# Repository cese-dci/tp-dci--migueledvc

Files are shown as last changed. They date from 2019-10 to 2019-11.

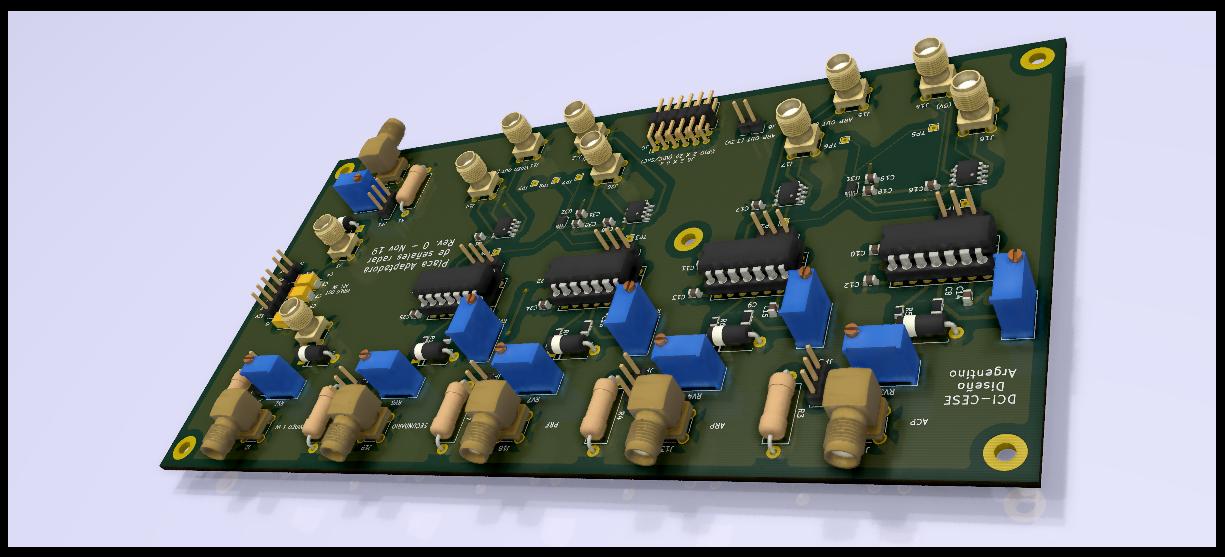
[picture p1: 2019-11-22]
adaptadora/img/4-adaptadora_entradas.jpg

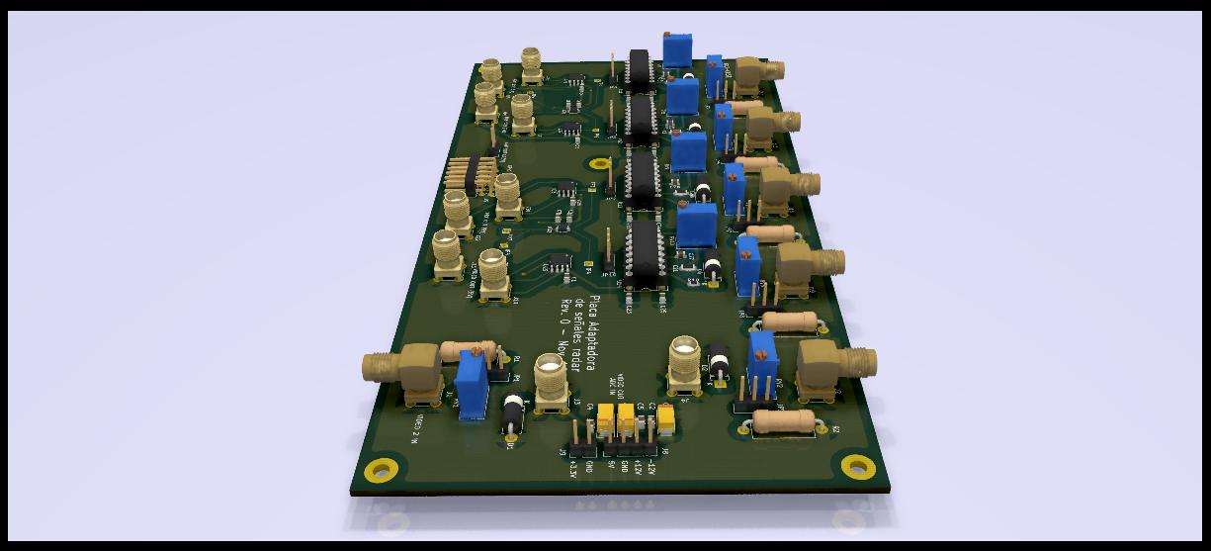
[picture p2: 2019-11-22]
adaptadora/img/6-adaptadora_videos.jpg

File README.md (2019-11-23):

#tp-dci--migueledvc

Placa adaptadora de señales de radar
====================================

+ El presente documento presenta la idea de un circuito adaptador de señales típicas de un radar.

+ No se especifica un modelo de radar en particular.

+ El circuíto es parte del desarrollo de un procesador de radar con tecnología FPGA-SoC. (ADC-SoC de Terasic)

+ Se utiliza para esta placa licencia "BSD 3-clause"

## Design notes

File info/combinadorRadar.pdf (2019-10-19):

# Placa adaptadora de Señales de Radar para la implementación de un combinador radar utilizando tecnología SoC-FPGA

# Introducción

La implementación de un Combinador Radar utilizando tecnología FPGA-SoC necesita de las señales de radar (videos de radar primario, videos de radar secundario, y señales de sincronismo). El sistema debe ser capaz combinar los datos extraídos de un sistema radar (Primario + Secundario) y entregar los datos ya procesados. La digitalización y el procesamiento lo debe realizar la tarjeta ADC-SoC de Terasic y la placa adaptadora debe facilitar las señales deseadas.

# Entradas

### - Videos analógicos (radar primario)

Mediante la emisión de pulsos y el cálculo del tiempo de viaje del pulso que se refleja, se puede conocer la posición de blancos, es el caso de los radares de tipo “primario”

### - Video Digital (radar secundario)

En este caso el radar de tipo secundario emite una señal de pregunta que el blanco debe responder con una nueva emisión y a partir de la cual se pueden extraer la posición (por cálculo del tiempo de viaje del pulso de respuesta) o por transmisión codificada de los datos (altura, código de aeronave, etc).

### - Señales de sincronismo:

- PRF: Pulse Repetition Frequency
En un radar del tipo pulsado es la cantidad de pulsos emitidos en un segundo.
- ACP: Azimuth-Change-Pulses
A partir de un encoder en la antena se cuentan una cantidad fija de pulsos. A partir del contador se deduce el ángulo acimutal. El contador se resetea con la señal ARP o NRP
- ARP: North Reference Pulse or Azimuth Reference Pulse
Señal de paso por el norte

# Salidas

Las salidas de la placa adaptadora que ingresan a la tarjeta ADC-SoC no deben superar los 3.3
V. Para esta placa en particular se agregan salidas duplicadas hacia otros procesadores.

Además se agregan salidas digitales hacia un DAC para verificar el correcto funcionamiento de los conversores A/D, una salida de ARP hacia el servidor de hora y salidas de video digital primario (que ya ha pasado por un filtro digital).

Es decir la placa provee las siguientes salidas:

### Video de Radar Primario Digital (x2)

### Video de Radar Secundario a la ADC/SoC (x1)

### Señales de sincronismo a la ADC/SoC (x1)

PRF

ACP

ARP

### Señales de sincronismo a otros procesadores (x2)

PRF

ACP

ARP

### Señal de ARP al servidor NTP (hora GPS para la ADC/SoC)

# Datos de interés

Ancho típico de blancos en video analógico: 0.5 μs

Ancho de pulso típico señales de sincronismo: 2 μs

Tensiones típicas video analógico: 3 V

Tensiones máximas señales de sincronismo: 40 V

# Tamaño

Se elige un tamaño estándar de PCB. Será determinado durante el diseño del PCB.

Opción empresa argentina: Medidas estandar DAI-ICHI (si es doble capa)

Opción con torno en emprendimiento local (si es simple capa)

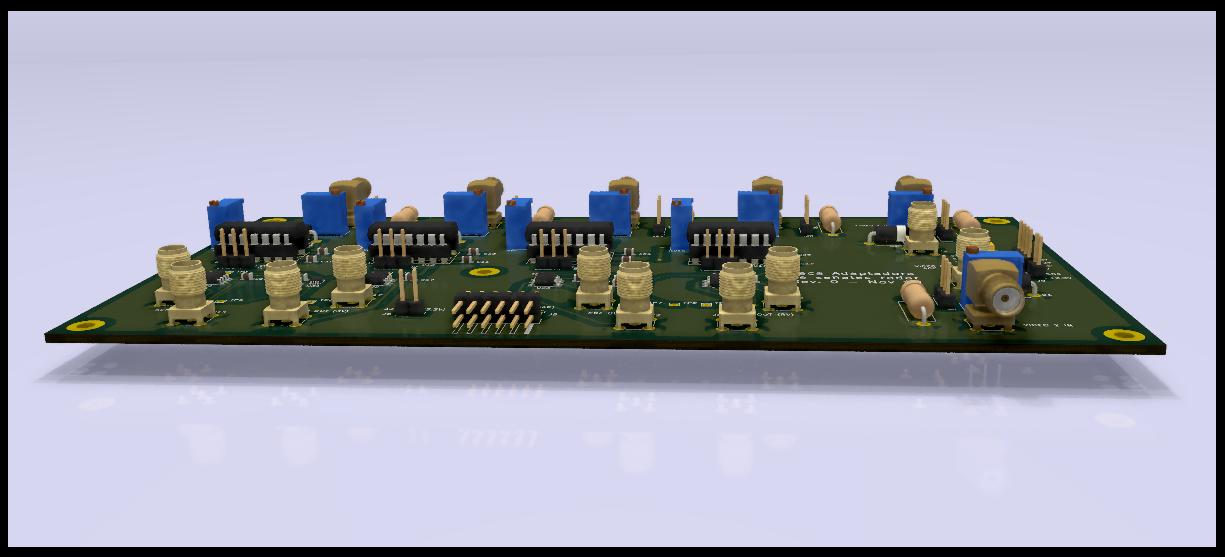
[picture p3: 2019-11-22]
adaptadora/img/5-adaptadora_salidas.jpg

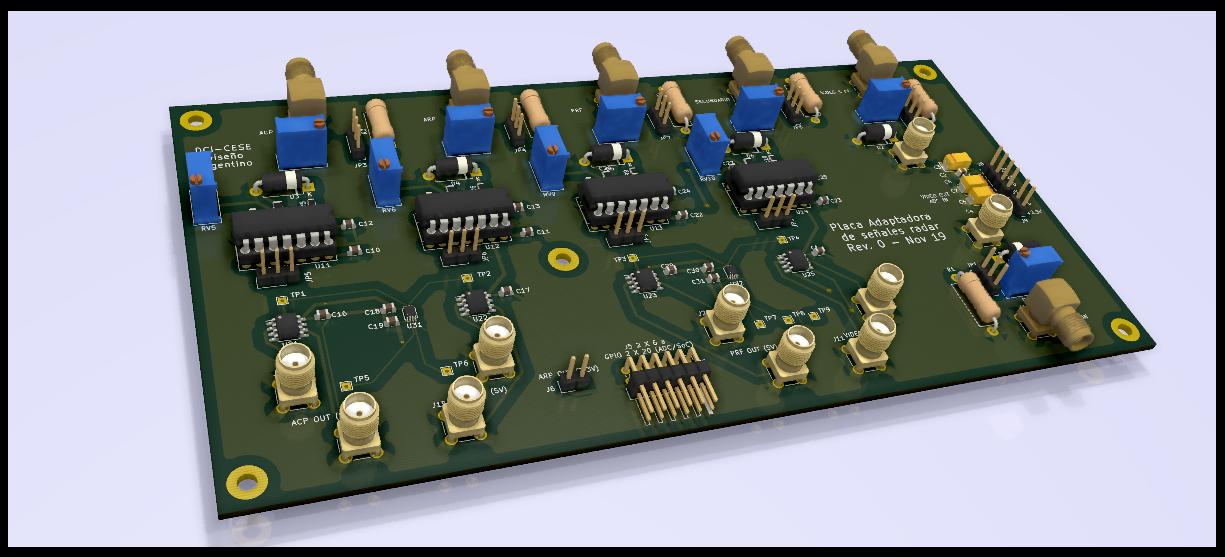
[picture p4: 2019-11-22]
adaptadora/img/3-adaptadora_rot.jpg

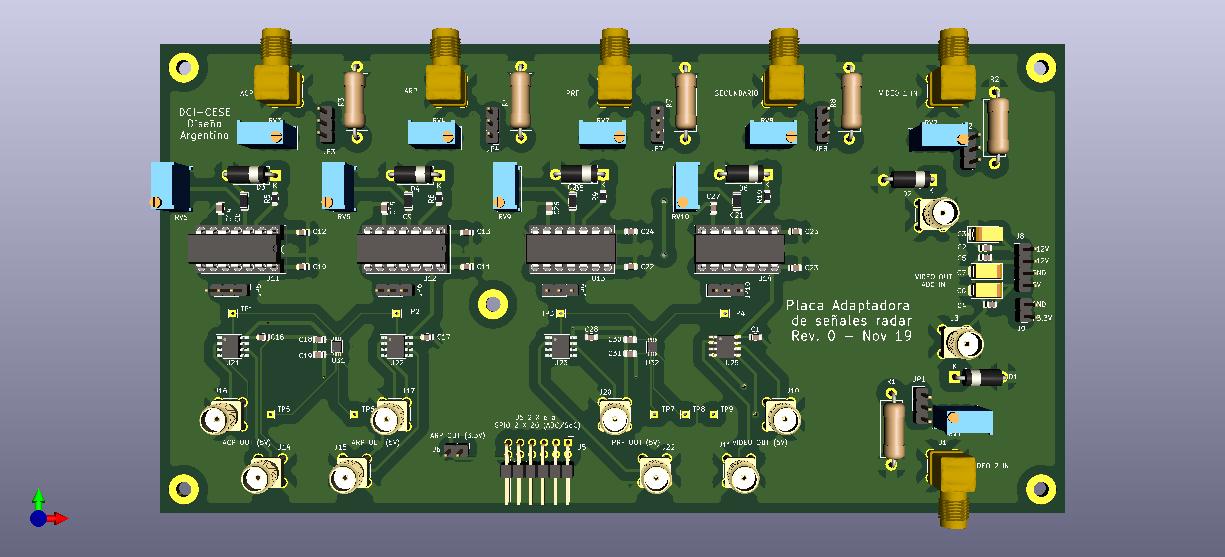
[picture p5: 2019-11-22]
adaptadora/img/1-adaptadora_f.jpg

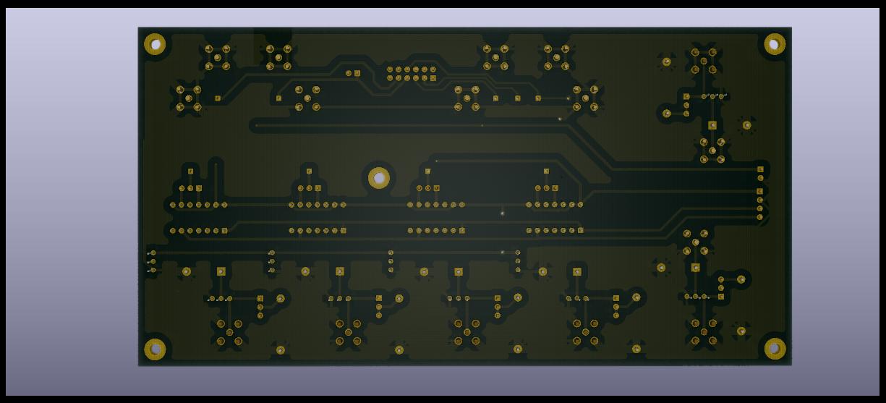
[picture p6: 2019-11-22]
adaptadora/img/2-adaptadora_b.jpg

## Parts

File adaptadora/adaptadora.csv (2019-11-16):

Source: | C:\Users\delar\tp-dci--migueledvc\adaptadora\adaptadora.sch
Date: | 8/11/2019 16:53:56
Tool: | Eeschema (5.1.4)-1
Component Count: | 102
Ref | Value | Footprint | Datasheet | Manufacturer | Vendor
C1 | 0_1uF-50V | Capacitor_SMD:C_0805_2012Metric | ~
C2 | 0_1uF-50V | Capacitor_SMD:C_0805_2012Metric | ~
C3 | 2_2uF-35V | Capacitor_Tantalum_SMD:CP_EIA-6032-28_Kemet-C | ~
C4 | 0_1uF-50V | Capacitor_SMD:C_0805_2012Metric | ~
C5 | 0_1uF-50V | Capacitor_SMD:C_0805_2012Metric | ~
C6 | 2_2uF-35V | Capacitor_Tantalum_SMD:CP_EIA-6032-28_Kemet-C | ~
C7 | 2_2uF-35V | Capacitor_Tantalum_SMD:CP_EIA-6032-28_Kemet-C | ~
C8 | 1uF-16V | Resistor_SMD:R_1206_3216Metric | ~
C9 | 1uF-16V | Resistor_SMD:R_1206_3216Metric | ~
C10 | 0_1uF-50V | Capacitor_SMD:C_0805_2012Metric | ~
C11 | 0_1uF-50V | Capacitor_SMD:C_0805_2012Metric | ~
C12 | 0_1uF-50V | Capacitor_SMD:C_0805_2012Metric | ~
C13 | 0_1uF-50V | Capacitor_SMD:C_0805_2012Metric | ~
C14 | 0_1uF-50V | Capacitor_SMD:C_0805_2012Metric | ~
C15 | 0_1uF-50V | Capacitor_SMD:C_0805_2012Metric | ~
C16 | 0_1uF-50V | Capacitor_SMD:C_0805_2012Metric | ~
C17 | 0_1uF-50V | Capacitor_SMD:C_0805_2012Metric | ~
C18 | 0_1uF-50V | Capacitor_SMD:C_0805_2012Metric | ~
C19 | 0_1uF-50V | Capacitor_SMD:C_0805_2012Metric | ~
C20 | 1uF-16V | Resistor_SMD:R_1206_3216Metric | ~
C21 | 1uF-16V | Resistor_SMD:R_1206_3216Metric | ~
C22 | 0_1uF-50V | Capacitor_SMD:C_0805_2012Metric | ~
C23 | 0_1uF-50V | Capacitor_SMD:C_0805_2012Metric | ~
C24 | 0_1uF-50V | Capacitor_SMD:C_0805_2012Metric | ~
C25 | 0_1uF-50V | Capacitor_SMD:C_0805_2012Metric | ~
C26 | 0_1uF-50V | Capacitor_SMD:C_0805_2012Metric | ~
C27 | 0_1uF-50V | Capacitor_SMD:C_0805_2012Metric | ~
C28 | 0_1uF-50V | Capacitor_SMD:C_0805_2012Metric | ~
C30 | 0_1uF-50V | Capacitor_SMD:C_0805_2012Metric | ~
C31 | 0_1uF-50V | Capacitor_SMD:C_0805_2012Metric | ~
D1 | D_TVS | Diode_SMD:D_0201_0603Metric | ~
D2 | D_TVS | Diode_SMD:D_0201_0603Metric | ~
D3 | D_TVS | Diode_SMD:D_0201_0603Metric | ~
D4 | D_TVS | Diode_SMD:D_0201_0603Metric | ~
D5 | D_TVS | Diode_SMD:D_0201_0603Metric | ~
D6 | D_TVS | Diode_SMD:D_0201_0603Metric | ~
H1 | MountingHole | MountingHole:MountingHole_3.2mm_M3_Pad | ~
H2 | MountingHole | MountingHole:MountingHole_3.2mm_M3_Pad | ~
H3 | MountingHole | MountingHole:MountingHole_3.2mm_M3_Pad | ~
H4 | MountingHole | MountingHole:MountingHole_3.2mm_M3_Pad | ~
H5 | MountingHole | MountingHole:MountingHole_3.2mm_M3_Pad | ~
J1 | Conn_Coaxial | Connector_Coaxial:SMA_Amphenol_901-144_Vertical | ~
J2 | Conn_Coaxial | Connector_Coaxial:SMA_Amphenol_901-144_Vertical | ~
J3 | Conn_Coaxial | Connector_Coaxial:SMA_Amphenol_901-144_Vertical | ~
J4 | Conn_Coaxial | Connector_Coaxial:SMA_Amphenol_901-144_Vertical | ~
J5 | Conn_02x20_Odd_Even | Connector_PinHeader_2.54mm:PinHeader_2x20_P2.54mm_Horizontal | ~
J6 | Conn_01x02 | Connector_PinHeader_2.54mm:PinHeader_1x02_P2.54mm_Vertical | ~
J7 | Conn_02x20_Odd_Even | Connector_PinHeader_2.00mm:PinHeader_2x20_P2.00mm_Vertical | ~
J8 | Conn_01x04 | Connector_PinHeader_2.54mm:PinHeader_1x04_P2.54mm_Vertical | ~
J9 | Conn_01x02 | Connector_PinHeader_2.54mm:PinHeader_1x02_P2.54mm_Vertical | ~
J10 | Conn_Coaxial | Connector_Coaxial:SMA_Amphenol_901-144_Vertical | ~
J11 | Conn_Coaxial | Connector_Coaxial:SMA_Amphenol_901-144_Vertical | ~
J12 | Conn_Coaxial | Connector_Coaxial:SMA_Amphenol_901-144_Vertical | ~
J13 | Conn_Coaxial | Connector_Coaxial:SMA_Amphenol_901-144_Vertical | ~
J14 | Conn_Coaxial | Connector_Coaxial:SMA_Amphenol_901-144_Vertical | ~
J15 | Conn_Coaxial | Connector_Coaxial:SMA_Amphenol_901-144_Vertical | ~
J16 | Conn_Coaxial | Connector_Coaxial:SMA_Amphenol_901-144_Vertical | ~
J17 | Conn_Coaxial | Connector_Coaxial:SMA_Amphenol_901-144_Vertical | ~
J18 | Conn_Coaxial | Connector_Coaxial:SMA_Amphenol_901-144_Vertical | ~
J19 | Conn_Coaxial | Connector_Coaxial:SMA_Amphenol_901-144_Vertical | ~
J20 | Conn_Coaxial | Connector_Coaxial:SMA_Amphenol_901-144_Vertical | ~
J22 | Conn_Coaxial | Connector_Coaxial:SMA_Amphenol_901-144_Vertical | ~
JP1 | Jumper_3_Open | Jumper:SolderJumper-3_P1.3mm_Open_Pad1.0x1.5mm_NumberLabels | ~
JP2 | Jumper_3_Open | Jumper:SolderJumper-3_P1.3mm_Open_Pad1.0x1.5mm_NumberLabels | ~
JP3 | Jumper_3_Open | Jumper:SolderJumper-3_P1.3mm_Open_Pad1.0x1.5mm_NumberLabels | ~
JP4 | Jumper_3_Open | Jumper:SolderJumper-3_P1.3mm_Open_Pad1.0x1.5mm_NumberLabels | ~
JP5 | Jumper_3_Open | Jumper:SolderJumper-3_P1.3mm_Open_Pad1.0x1.5mm_NumberLabels | ~
JP6 | Jumper_3_Open | Jumper:SolderJumper-3_P1.3mm_Open_Pad1.0x1.5mm_NumberLabels | ~
JP7 | Jumper_3_Open | Jumper:SolderJumper-3_P1.3mm_Open_Pad1.0x1.5mm_NumberLabels | ~
JP8 | Jumper_3_Open | Jumper:SolderJumper-3_P1.3mm_Open_Pad1.0x1.5mm_NumberLabels | ~
JP9 | Jumper_3_Open | Jumper:SolderJumper-3_P1.3mm_Open_Pad1.0x1.5mm_NumberLabels | ~
JP10 | Jumper_3_Open | Jumper:SolderJumper-3_P1.3mm_Open_Pad1.0x1.5mm_NumberLabels | ~
R1 | 50 - 1/2W - 5% | Resistor_THT:R_Axial_DIN0414_L11.9mm_D4.5mm_P15.24mm_Horizontal | ~
R2 | 50 - 1/2W - 5% | Resistor_THT:R_Axial_DIN0414_L11.9mm_D4.5mm_P15.24mm_Horizontal | ~
R3 | 50 - 1/2W - 5% | Resistor_THT:R_Axial_DIN0414_L11.9mm_D4.5mm_P15.24mm_Horizontal | ~
R4 | 50 - 1/2W - 5% | Resistor_THT:R_Axial_DIN0414_L11.9mm_D4.5mm_P15.24mm_Horizontal | ~
R5 | 100 - 1/8W - 5% | Resistor_SMD:R_0805_2012Metric | ~
R6 | 100 - 1/8W - 5% | Resistor_SMD:R_0805_2012Metric | ~
R7 | 50 - 1/2W - 5% | Resistor_THT:R_Axial_DIN0414_L11.9mm_D4.5mm_P15.24mm_Horizontal | ~
R8 | 50 - 1/2W - 5% | Resistor_THT:R_Axial_DIN0414_L11.9mm_D4.5mm_P15.24mm_Horizontal | ~
R9 | 100 - 1/8W - 5% | Resistor_SMD:R_0805_2012Metric | ~
R10 | 100 - 1/8W - 5% | Resistor_SMD:R_0805_2012Metric | ~
RV1 | R_POT | Potentiometer_THT:Potentiometer_Bourns_3296W_Vertical | ~
RV2 | R_POT | Potentiometer_THT:Potentiometer_Bourns_3296W_Vertical | ~
RV3 | R_POT | Potentiometer_THT:Potentiometer_Bourns_3296W_Vertical | ~
RV4 | R_POT | Potentiometer_THT:Potentiometer_Bourns_3296W_Vertical | ~
RV5 | R_POT | Potentiometer_THT:Potentiometer_Bourns_3296W_Vertical | ~
RV6 | R_POT | Potentiometer_THT:Potentiometer_Bourns_3296W_Vertical | ~
RV7 | R_POT | Potentiometer_THT:Potentiometer_Bourns_3296W_Vertical | ~
RV8 | R_POT | Potentiometer_THT:Potentiometer_Bourns_3296W_Vertical | ~
RV9 | R_POT | Potentiometer_THT:Potentiometer_Bourns_3296W_Vertical | ~
RV10 | R_POT | Potentiometer_THT:Potentiometer_Bourns_3296W_Vertical | ~
U11 | LM361MX_NOPB | Package_SO:SOIC-14_3.9x8.7mm_P1.27mm | http://www.ti.com/lit/ds/symlink/lm361.pdf
U12 | LM361MX_NOPB | Package_SO:SOIC-14_3.9x8.7mm_P1.27mm | http://www.ti.com/lit/ds/symlink/lm361.pdf
U13 | LM361MX_NOPB | Package_SO:SOIC-14_3.9x8.7mm_P1.27mm | http://www.ti.com/lit/ds/symlink/lm361.pdf
U14 | LM361MX_NOPB | Package_SO:SOIC-14_3.9x8.7mm_P1.27mm | http://www.ti.com/lit/ds/symlink/lm361.pdf
U21 | TLV2772IDR | Package_SO:SOIC-8_3.9x4.9mm_P1.27mm | http://www.ti.com/lit/ds/symlink/tlv2772.pdf
U22 | TLV2772IDR | Package_SO:SOIC-8_3.9x4.9mm_P1.27mm | http://www.ti.com/lit/ds/symlink/tlv2772.pdf
U23 | TLV2772IDR | Package_SO:SOIC-8_3.9x4.9mm_P1.27mm | http://www.ti.com/lit/ds/symlink/tlv2772.pdf
U25 | TLV2772IDR | Package_SO:SOIC-8_3.9x4.9mm_P1.27mm | http://www.ti.com/lit/ds/symlink/tlv2772.pdf
U31 | SN74LVC2T45DCUR | Package_SO:VSSOP-8_2.4x2.1mm_P0.5mm | http://www.ti.com/lit/ds/symlink/sn74lvc2t45.pdf
U32 | SN74LVC2T45DCUR | Package_SO:VSSOP-8_2.4x2.1mm_P0.5mm | http://www.ti.com/lit/ds/symlink/sn74lvc2t45.pdf

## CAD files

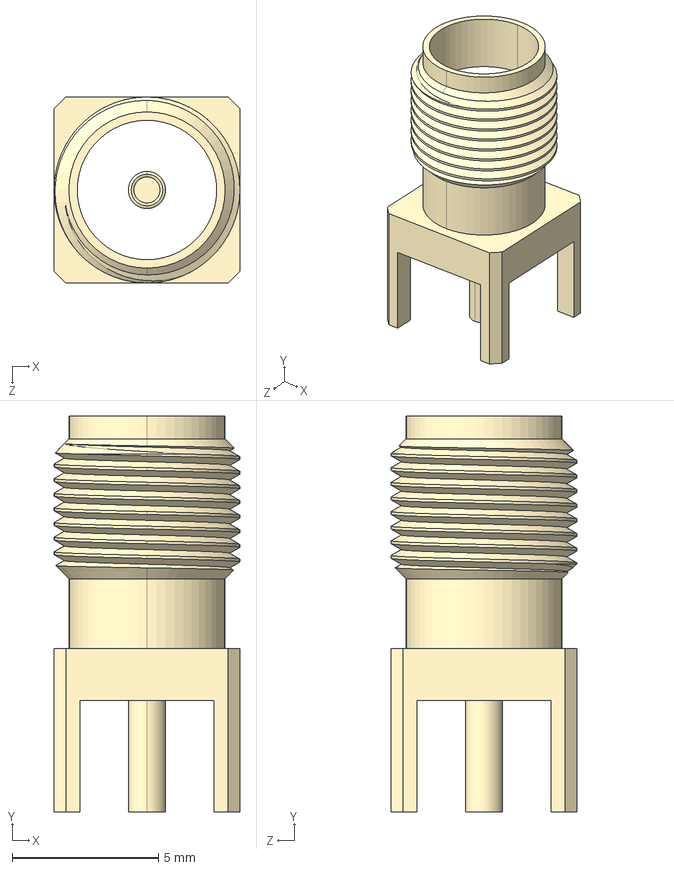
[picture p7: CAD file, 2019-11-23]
adaptadora/shapes3D/User Library-5-1814832-1.STEP
6.35 x 13.5 x 6.35 mm

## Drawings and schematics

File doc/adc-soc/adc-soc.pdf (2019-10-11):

PAGE | CONTENT
01 | Cover Page

ADC-SoC Development Board

02 | Block Diagram
03 | FPGA IO Bank3, 4, 5 and 8
04 | FPGA IO Bank 6 (HPS DDR3)
05 | FPGA IO Bank 7 (HPS Peripheral Device)
06 | FPGA Clock In/Out and Clock Generator
07 | FPGA Configuration and EPCS device
08 | FPGA Power
09 | FPGA Decoupling
10 | USB Blaster II
11 | JTAG Chain
12 | HPS Peripheral : DDR3 SDRAM
13 | HPS Peripheral : UART to USB and SD Card Socket
14 | HPS Peripheral : USB OTG
15 | HPS Peripheral : Gagabit Ethernet
16 | HPS Peripheral : Accelerometer & LTC Expansion Header
17 | HPS Peripheral : Reset Circuit, Button and LED
18 | FPGA : ADC1 (LTC2308) for 8-channel Analog Expansion Header and Arduino Analog input
19 | FPGA : GPIO, Analog and Arduino UNO Expansion Header
20 | FPGA : Button, Switch and LED
21 | FPGA : ADC A
22 | FPGA : ADC B
23 | Power - 1.1V, 5V
24 | Power - 2.5V, 3.3V
25 | Power - 1.2V, 1.5V, 1.8V, 9V

Copyright (c) 2015 by Terasic Inc. Taiwan.
All rights reserved.
No part of this schematic design may be reproduced, duplicated, or used without the prior written permission of Terasic.
ADC-SoC Board

Size Size Size B B B | Document Number Document Number Document Number Cover Page Cover Page Cover Page | Rev Rev Rev A0 A0 A0

Date: Tuesday, December 20, 2016 Tuesday, December 20, 2016 Tuesday, December 20, 2016 | Sheet 1 1 1 of 25 25 25

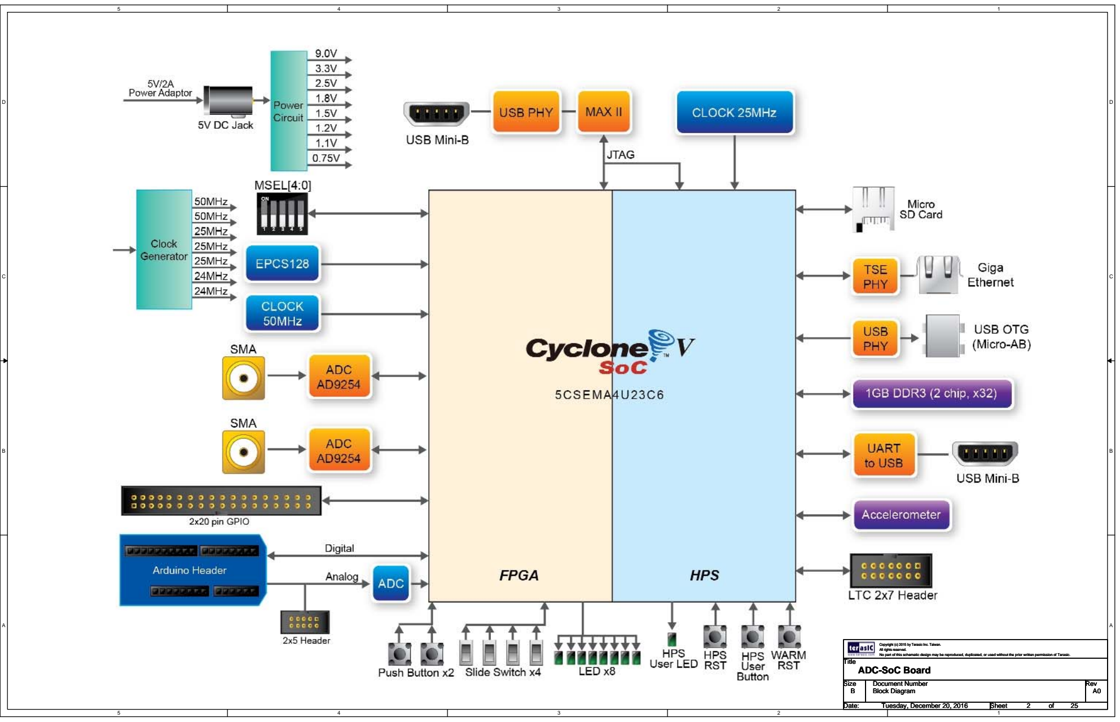
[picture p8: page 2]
Title Title; Title

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

Size Size Size B B B | Document Number Document Number Document Number Block Diagram Block Diagram Block Diagram | Rev Rev Rev A0 A0 A0

Tuesday, December 20, 2016 Tuesday, December 20, 2016 Tuesday, December 20, 2016 | 2 2 2 25 25 25

## CYCLONE V SoC BANK 3

## CYCLONE V SoC BANK 4

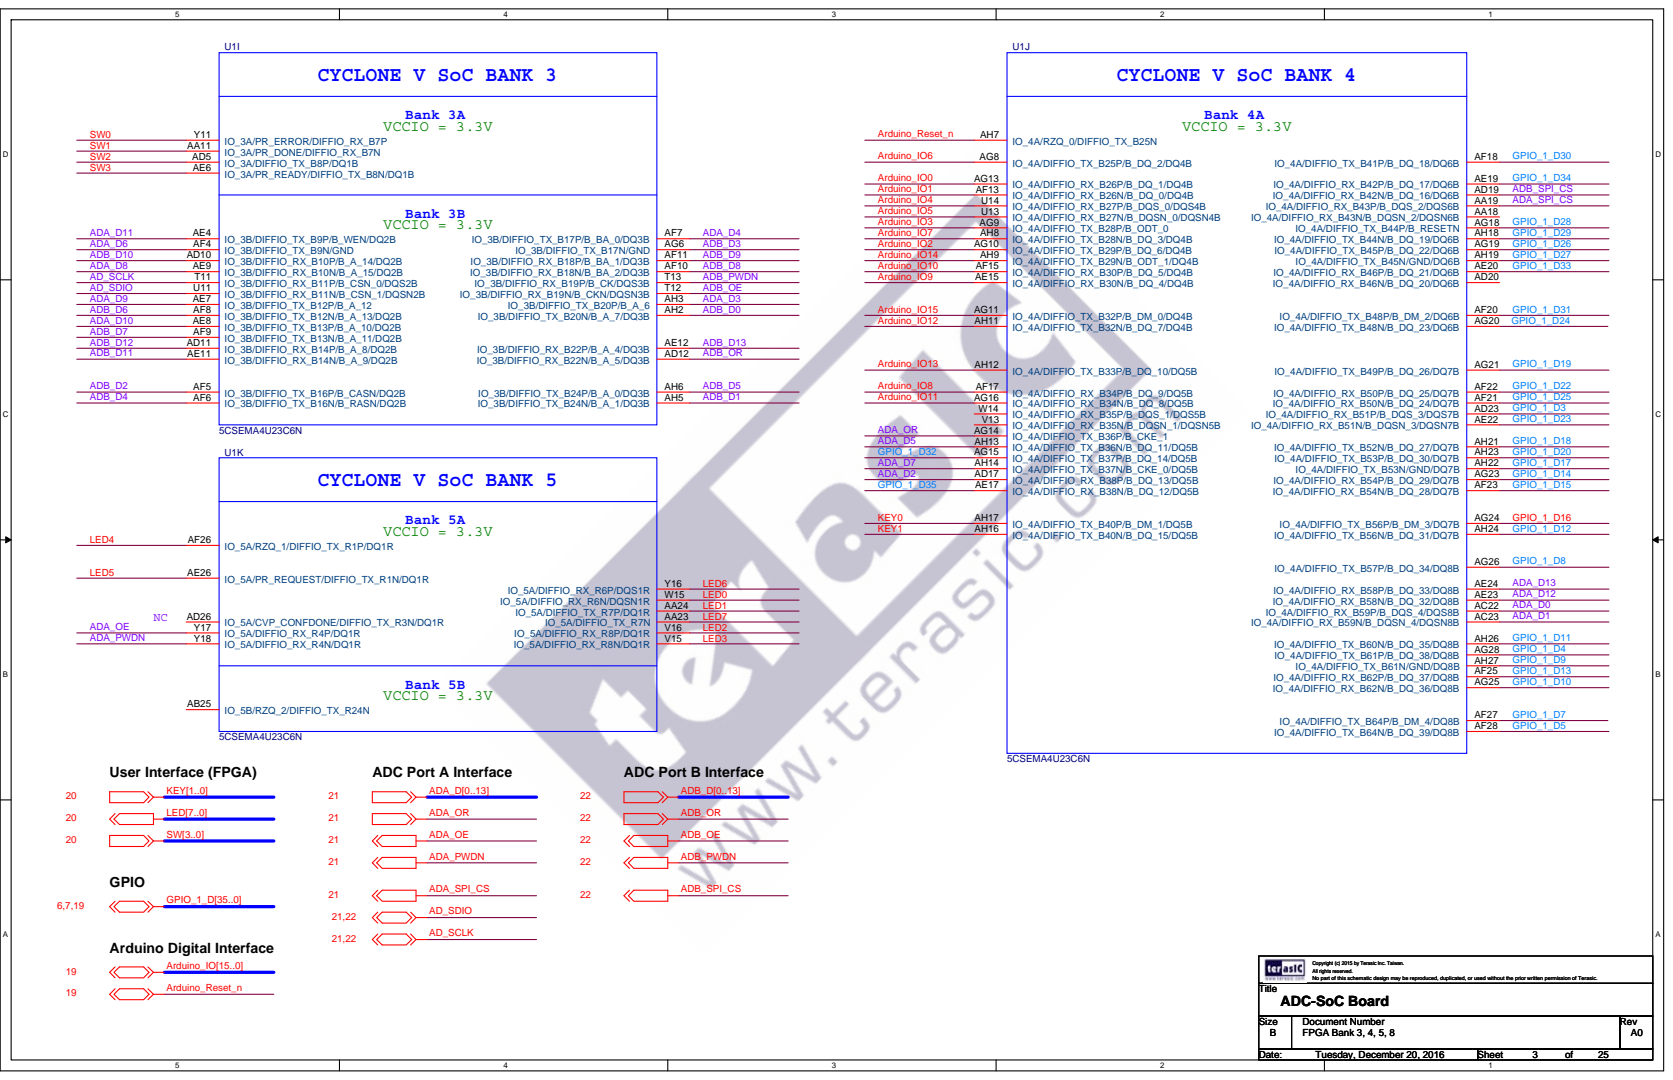
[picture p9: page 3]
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

Size Size Size B B B | Document Number Document Number Document Number FPGA Bank 3, 4, 5, 8 FPGA Bank 3, 4, 5, 8 FPGA Bank 3, 4, 5, 8 | Rev Rev Rev A0 A0 A0

Tuesday, December 20, 2016 Tuesday, December 20, 2016 Tuesday, December 20, 2016 | 3 3 3 25 25 25

## DDR3 Interface (HPS) CYCLONE V SoC BANK 6 (HPS)

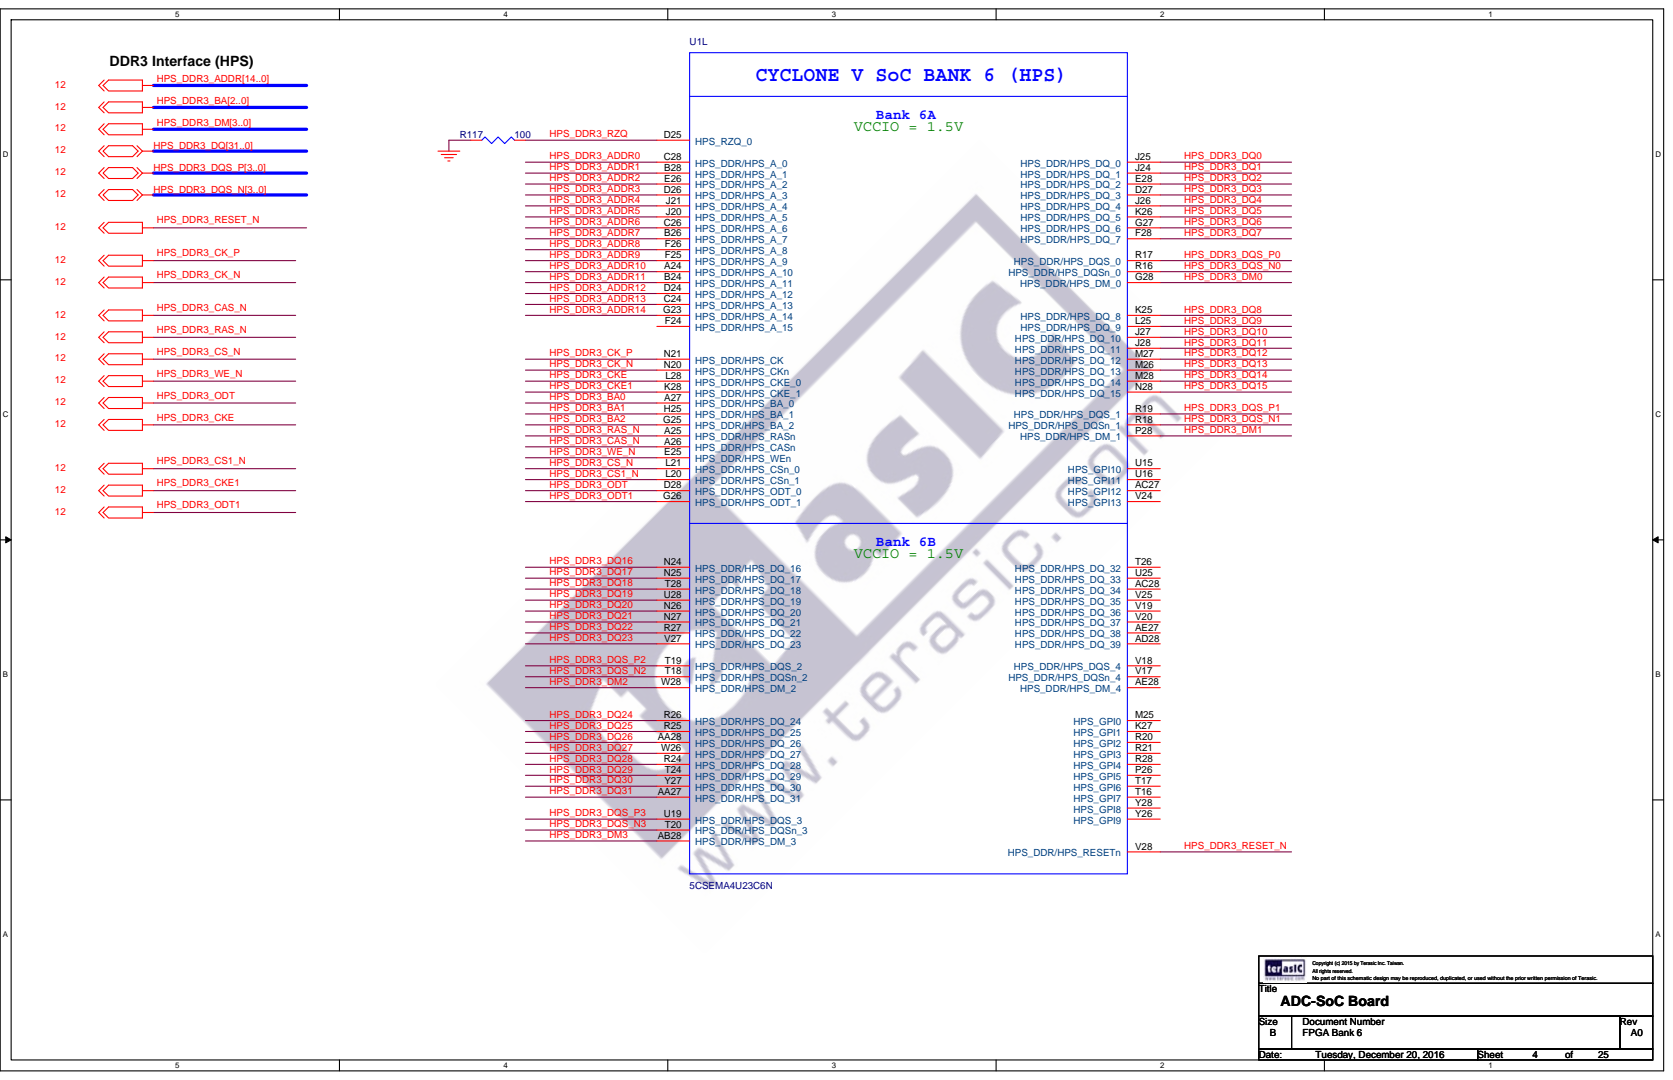
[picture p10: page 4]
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

Size Size Size B B B | Document Number Document Number Document Number FPGA Bank 6 FPGA Bank 6 FPGA Bank 6 | Rev Rev Rev A0 A0 A0

Tuesday, December 20, 2016 Tuesday, December 20, 2016 Tuesday, December 20, 2016 | 4 4 4 25 25 25

## UBS PHY Interface (ULPI)

## Ethernet PHY Interface (RGMII)

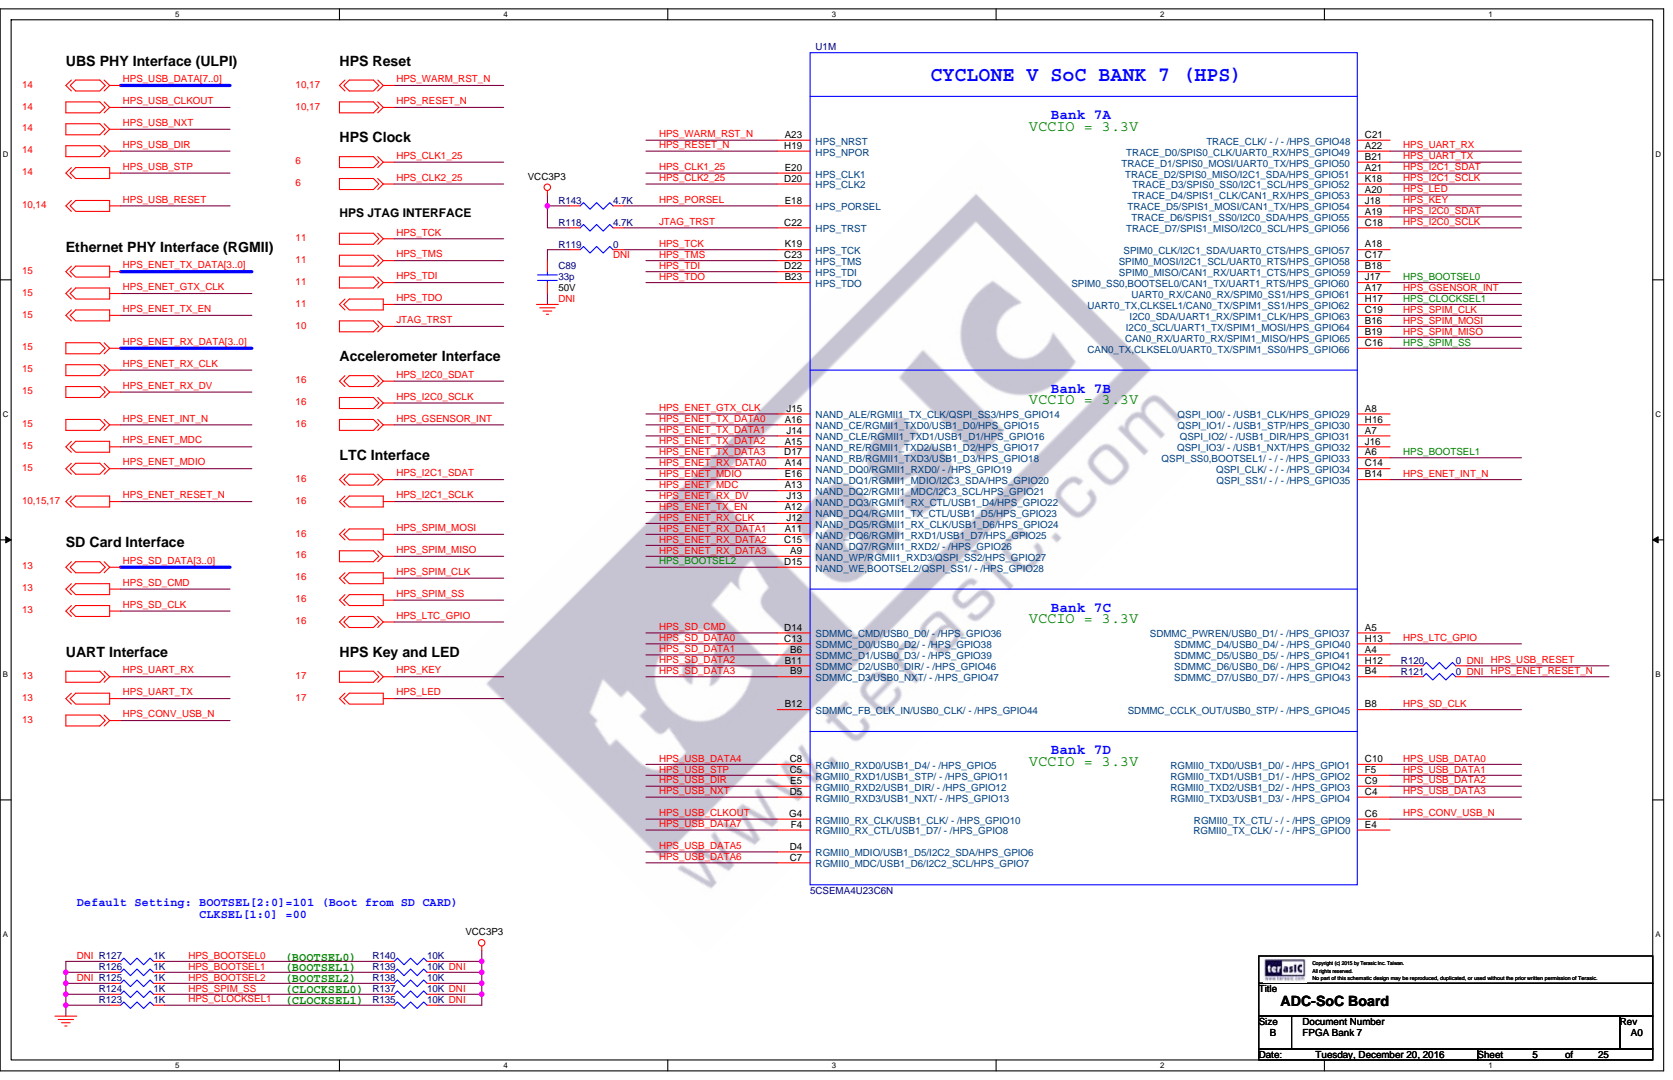
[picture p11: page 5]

CYCLONE V SoC BANK 7 (HPS)

HPS Key and LED

Default Setting: BOOTSEL[2:0]=101 (Boot from SD CARD)

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

Size Size Size B B B | Document Number Document Number Document Number FPGA Bank 7 FPGA Bank 7 FPGA Bank 7 | Rev Rev Rev A0 A0 A0

Tuesday, December 20, 2016 Tuesday, December 20, 2016 Tuesday, December 20, 2016 | 5 5 5 25 25 25

## GPIO

## ADC Port A Interface

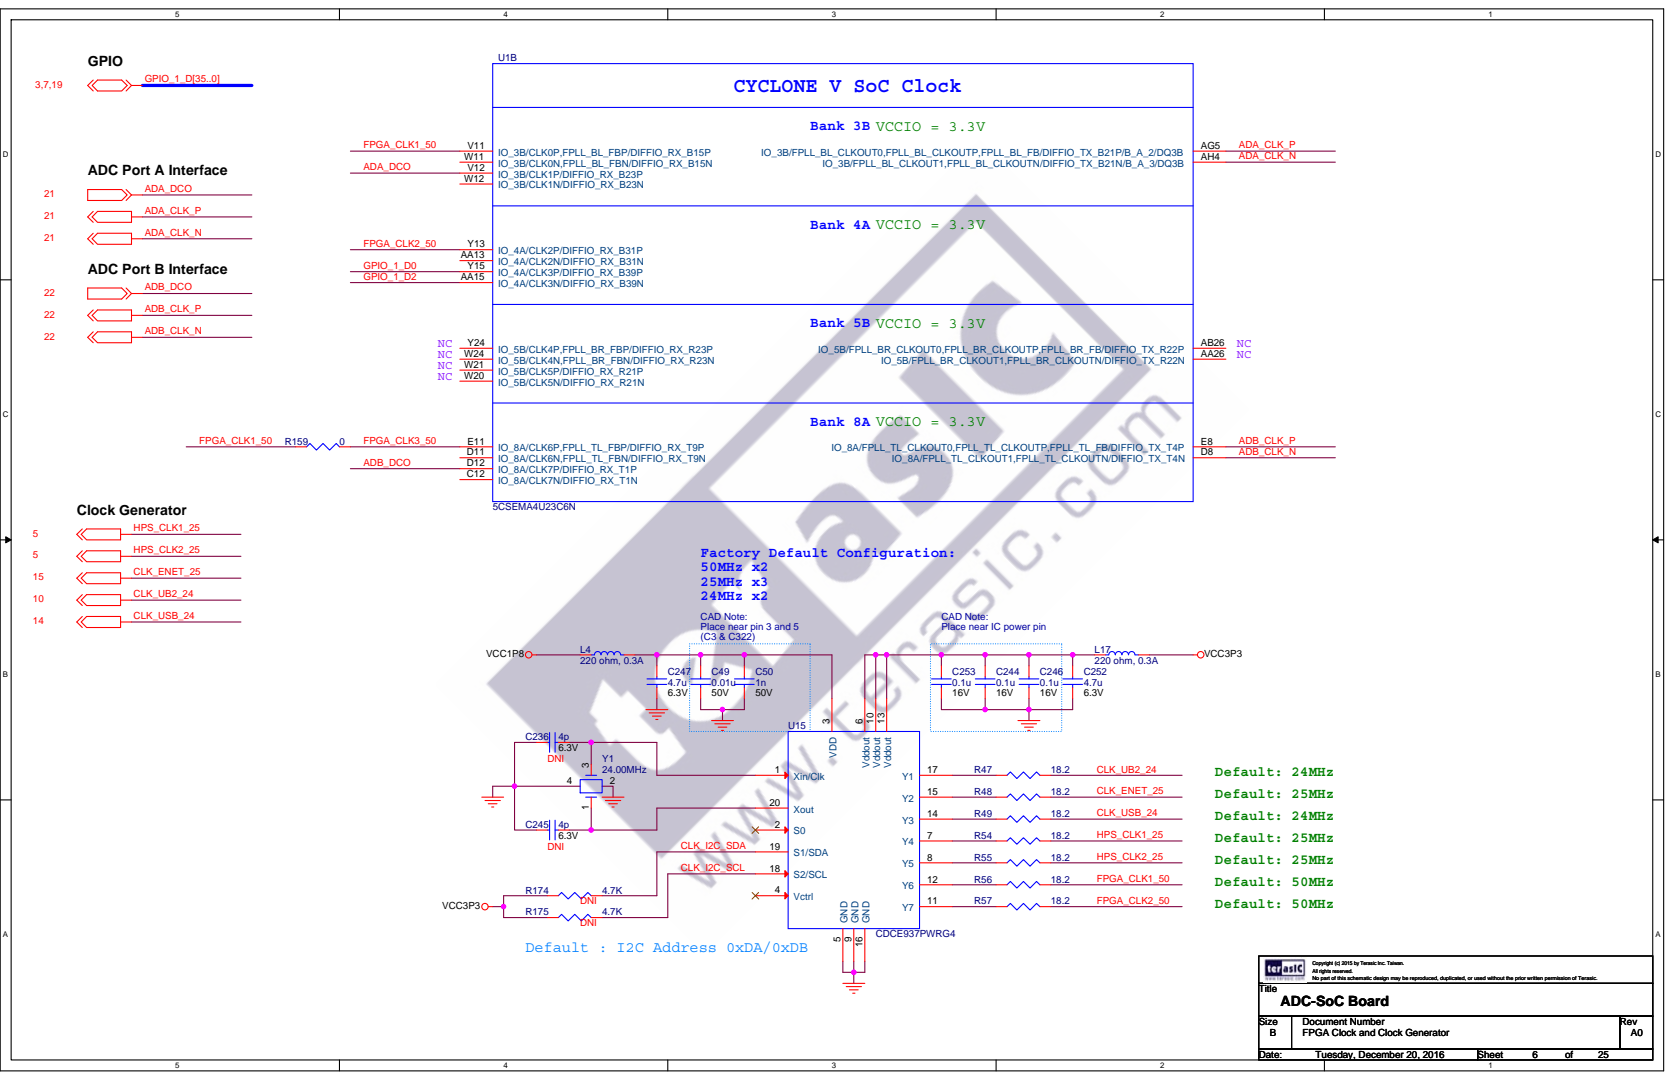
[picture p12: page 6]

CAD Note:
Place near IC power pin

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

Size Size Size B B B | Document Number Document Number Document Number FPGA Clock and Clock Generator FPGA Clock and Clock Generator FPGA Clock and Clock Generator | Rev Rev Rev A0 A0 A0

Tuesday, December 20, 2016 Tuesday, December 20, 2016 Tuesday, December 20, 2016 | 6 6 6 25 25 25

## USB Blaster
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

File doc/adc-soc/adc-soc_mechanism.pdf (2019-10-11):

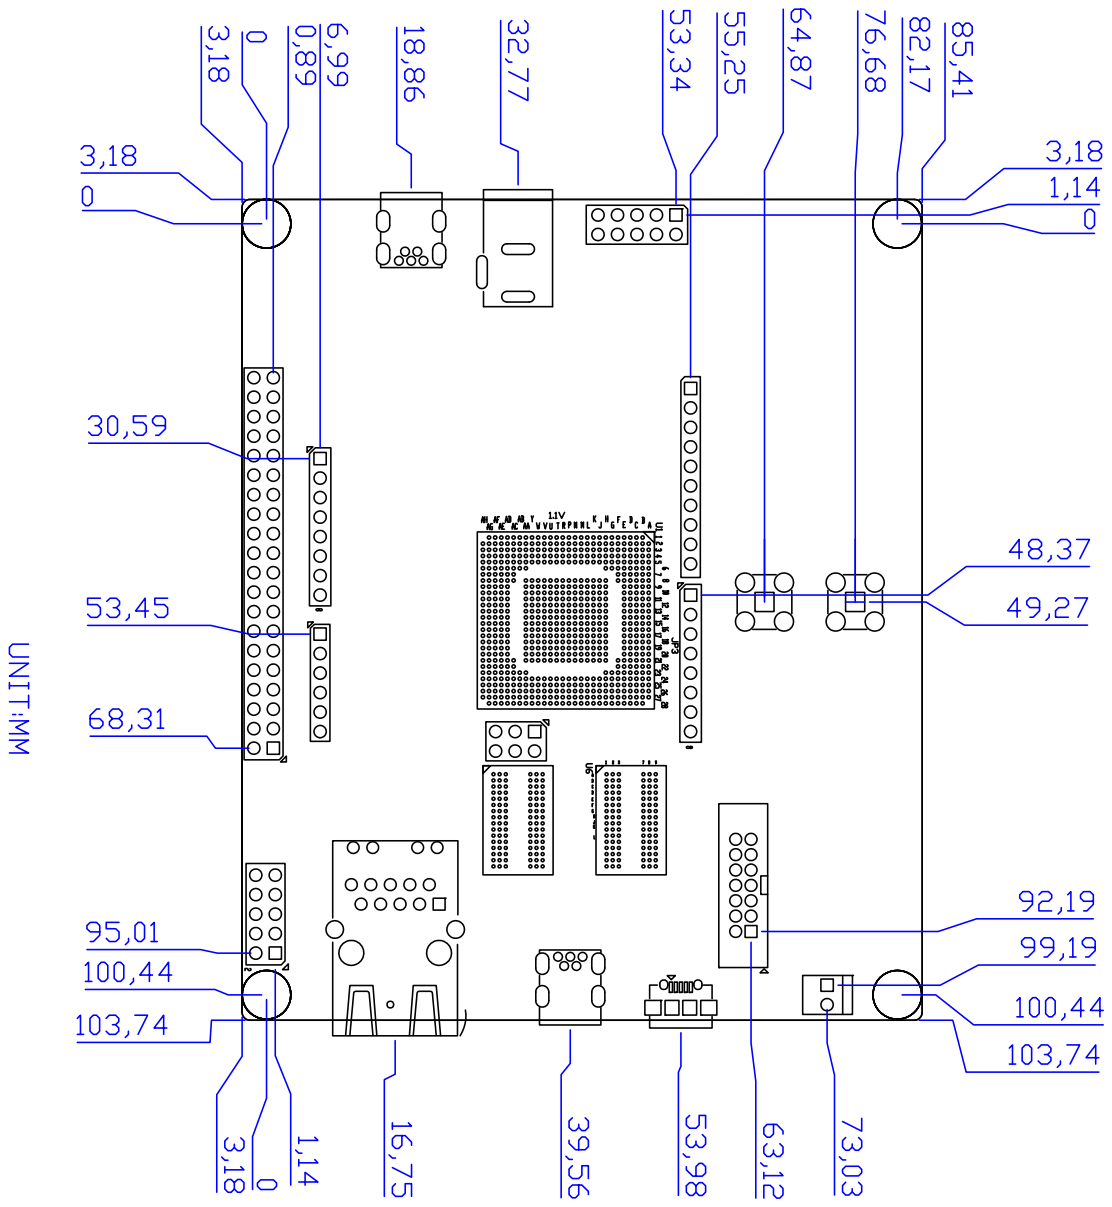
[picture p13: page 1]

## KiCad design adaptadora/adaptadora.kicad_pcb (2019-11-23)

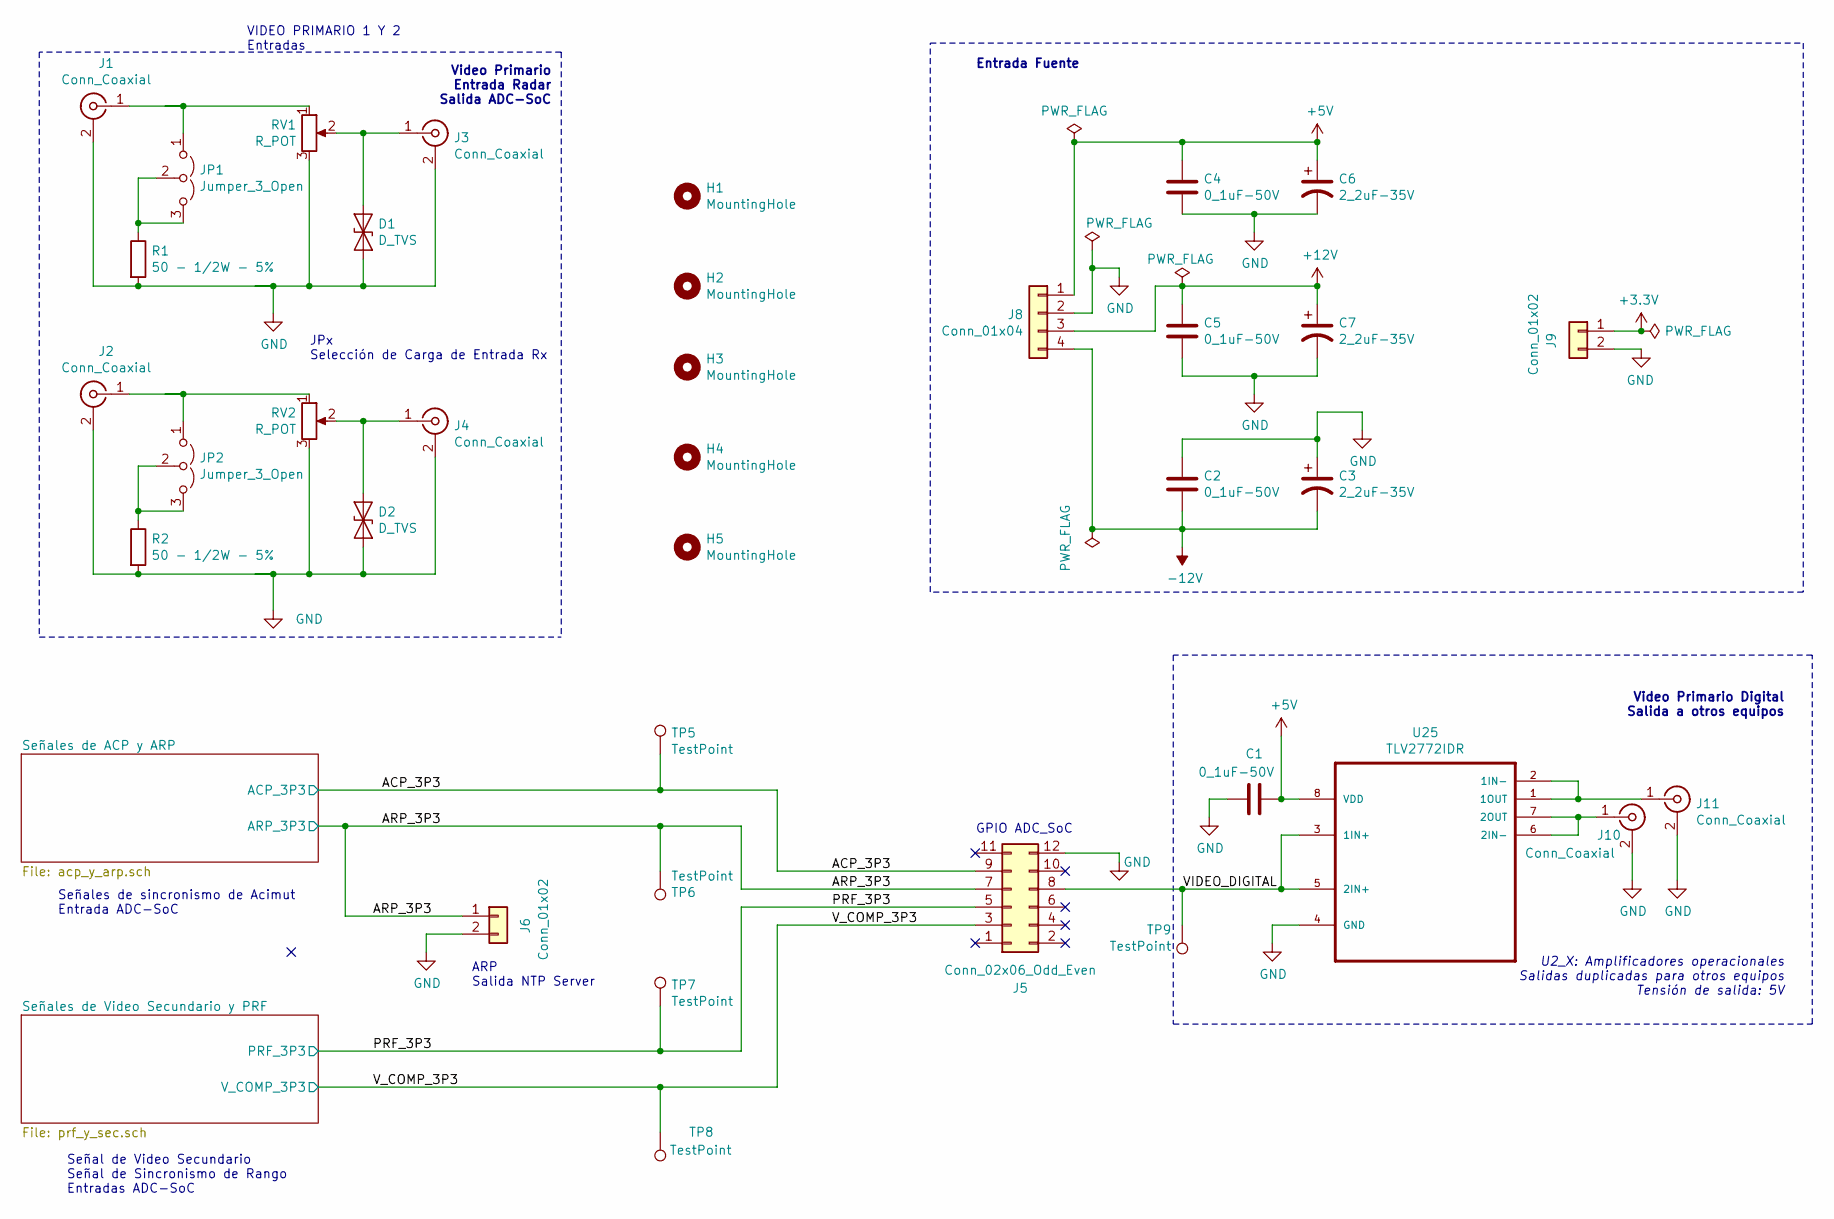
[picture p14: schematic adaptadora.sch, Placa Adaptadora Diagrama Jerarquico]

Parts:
C1, C2, C4, C5: 0_1uF-50V; C_0805_2012Metric
C3, C6, C7: 2_2uF-35V; CP_EIA-6032-28_Kemet-C
D1, D2: D_TVS; D_DO-15_P10.16mm_Horizontal
H1, H2, H3, H4, H5: MountingHole; MountingHole_3.2mm_M3_Pad
J1, J2, J3, J4, J10, J11: Conn_Coaxial; SMA_Amphenol_901-144_Vertical
J5: Conn_02x06_Odd_Even; PinHeader_2x06_P2.54mm_Horizontal
J6, J9: Conn_01x02; PinHeader_1x02_P2.54mm_Vertical
J8: Conn_01x04; PinHeader_1x04_P2.54mm_Vertical
JP1, JP2: Jumper_3_Open; PinHeader_1x03_P2.54mm_Vertical
R1, R2: 50 - 1/2W - 5%; R_Axial_DIN0414_L11.9mm_D4.5mm_P15.24mm_Horizontal
RV1, RV2: R_POT; Potentiometer_Bourns_3296W_Vertical
TP5, TP6, TP7, TP8, TP9: TestPoint; TestPoint_THTPad_1.5x1.5mm_Drill0.7mm
U25: TLV2772IDR; SOIC-8_3.9x4.9mm_P1.27mm

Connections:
+3V3: J9.1; also elsewhere on the board
+5V: C1.1, C4.1, C6.1, J8.1, U25.8 (VDD); also elsewhere on the board
+12V: C5.1, C7.1, J8.3; also elsewhere on the board
-12V: C2.2, C3.2, J8.4; also elsewhere on the board
/ACP_3P3: J5.9, TP5.1; also elsewhere on the board
/ARP_3P3: J5.7, J6.1, TP6.1; also elsewhere on the board
/PRF_3P3: J5.5, TP7.1; also elsewhere on the board
/VIDEO_DIGITAL: J5.8, TP9.1, U25.3 (1IN+), U25.5 (2IN+)
/V_COMP_3P3: J5.3, TP8.1; also elsewhere on the board
GND: C1.2, C2.1, C3.1, C4.2, C5.2, C6.2, C7.2, D1.2 (A2), D2.2 (A2), J1.2 (Ext), J2.2 (Ext), J3.2 (Ext), J4.2 (Ext), J5.12, J6.2, J8.2, J9.2, J10.2 (Ext), J11.2 (Ext), R1.2, R2.2, RV1.3, RV2.3, U25.4 (GND); also elsewhere on the board
unnamed: D1.1 (A1), J3.1 (In), RV1.2
unnamed: D2.1 (A1), J4.1 (In), RV2.2
unnamed: J1.1 (In), JP1.1 (A), RV1.1
unnamed: J2.1 (In), JP2.1 (A), RV2.1
unnamed: J10.1 (In), U25.6 (2IN-), U25.7 (2OUT)
unnamed: J11.1 (In), U25.1 (1OUT), U25.2 (1IN-)
unnamed: JP1.2 (C), JP1.3 (B), R1.1
unnamed: JP2.2 (C), JP2.3 (B), R2.1

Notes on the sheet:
VIDEO PRIMARIO 1 Y 2 Entradas
Video Primario Entrada Radar Salida ADC-SoC
Señales de sincronismo de Acimut Entrada ADC-SoC
GPIO ADC_SoC
ARP Salida NTP Server
Video Primario Digital Salida a otros equipos
Entrada Fuente
Señal de Video Secundario Señal de Sincronismo de Rango Entradas ADC-SoC
U2_X: Amplificadores operacionales Salidas duplicadas para otros equipos Tensión de salida: 5V
JPx Selección de Carga de Entrada Rx

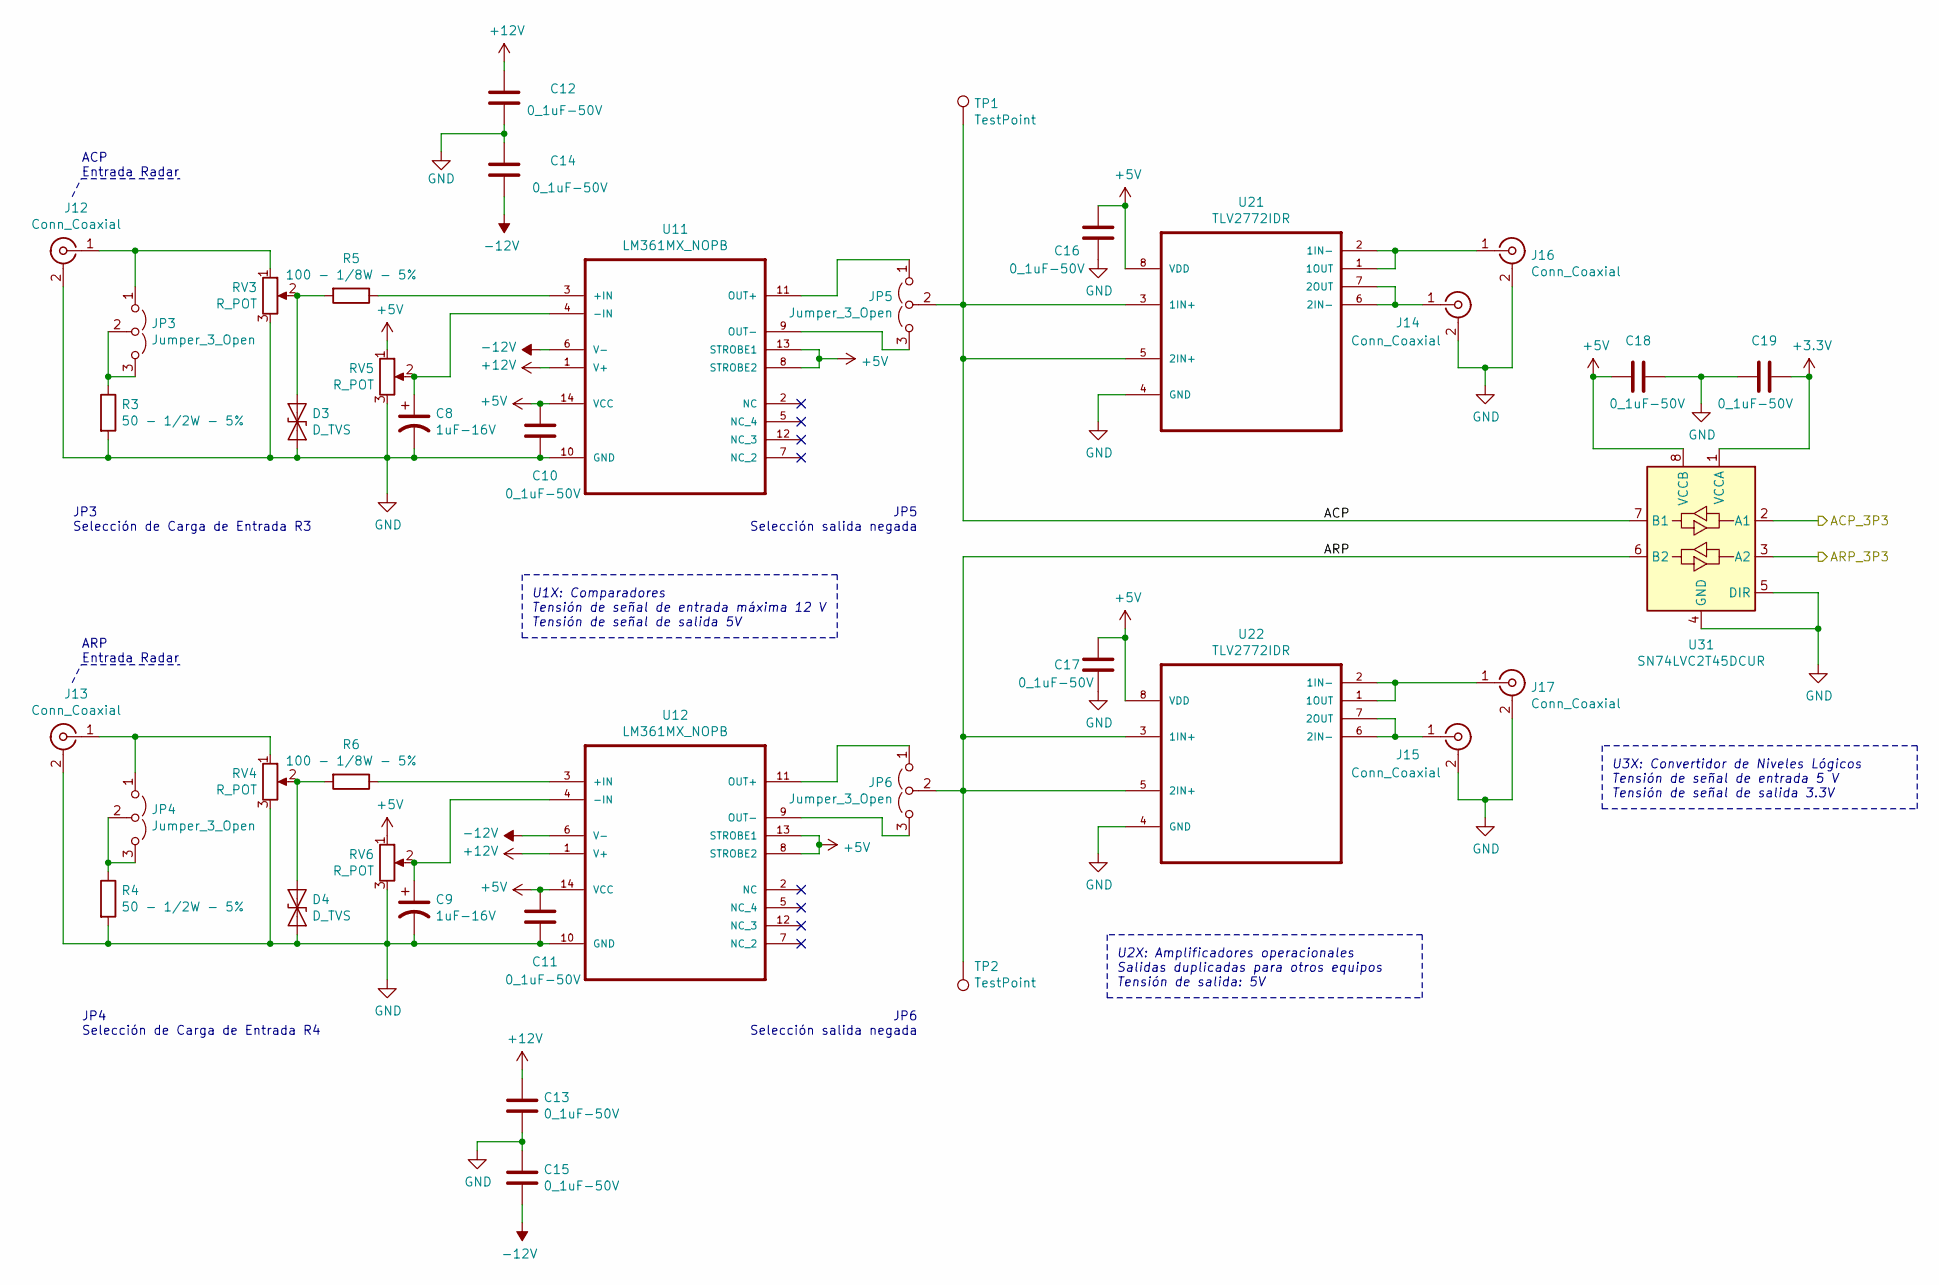
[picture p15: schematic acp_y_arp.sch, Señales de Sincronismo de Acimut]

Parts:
C8, C9: 1uF-16V; R_1206_3216Metric
C10, C11, C12, C13, C14, C15, C16, C17, C18, C19: 0_1uF-50V; C_0805_2012Metric
D3, D4: D_TVS; D_DO-15_P10.16mm_Horizontal
J12, J13, J14, J15, J16, J17: Conn_Coaxial; SMA_Amphenol_901-144_Vertical
JP3, JP4, JP5, JP6: Jumper_3_Open; PinHeader_1x03_P2.54mm_Vertical
R3, R4: 50 - 1/2W - 5%; R_Axial_DIN0414_L11.9mm_D4.5mm_P15.24mm_Horizontal
R5, R6: 100 - 1/8W - 5%; R_0805_2012Metric
RV3, RV4, RV5, RV6: R_POT; Potentiometer_Bourns_3296W_Vertical
TP1, TP2: TestPoint; TestPoint_THTPad_1.5x1.5mm_Drill0.7mm
U11, U12: LM361MX_NOPB; DIP-14_W7.62mm_Socket
U21, U22: TLV2772IDR; SOIC-8_3.9x4.9mm_P1.27mm
U31: SN74LVC2T45DCUR; VSSOP-8_2.4x2.1mm_P0.5mm

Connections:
+3V3: C19.1, U31.1 (VCCA); also elsewhere on the board
+5V: C10.2, C11.2, C16.1, C17.1, C18.2, RV5.1, RV6.1, U11.8 (STROBE2), U11.13 (STROBE1), U11.14 (VCC), U12.8 (STROBE2), U12.13 (STROBE1), U12.14 (VCC), U21.8 (VDD), U22.8 (VDD), U31.8 (VCCB); also elsewhere on the board
+12V: C12.1, C13.1, U11.1 (V+), U12.1 (V+); also elsewhere on the board
-12V: C14.2, C15.2, U11.6 (V-), U12.6 (V-); also elsewhere on the board
/ACP_3P3: U31.2 (A1); also elsewhere on the board
/ARP_3P3: U31.3 (A2); also elsewhere on the board
/Señales de ACP y ARP/ACP: JP5.2 (C), TP1.1, U21.3 (1IN+), U21.5 (2IN+), U31.7 (B1)
/Señales de ACP y ARP/ARP: JP6.2 (C), TP2.1, U22.3 (1IN+), U22.5 (2IN+), U31.6 (B2)
GND: C8.2, C9.2, C10.1, C11.1, C12.2, C13.2, C14.1, C15.1, C16.2, C17.2, C18.1, C19.2, D3.2 (A2), D4.2 (A2), J12.2 (Ext), J13.2 (Ext), J14.2 (Ext), J15.2 (Ext), J16.2 (Ext), J17.2 (Ext), R3.2, R4.2, RV3.3, RV4.3, RV5.3, RV6.3, U11.10 (GND), U12.10 (GND), U21.4 (GND), U22.4 (GND), U31.4 (GND), U31.5 (DIR); also elsewhere on the board
unnamed: C8.1, RV5.2, U11.4 (-IN)
unnamed: C9.1, RV6.2, U12.4 (-IN)
unnamed: D3.1 (A1), R5.2, RV3.2
unnamed: D4.1 (A1), R6.2, RV4.2
unnamed: J12.1 (In), JP3.1 (A), RV3.1
unnamed: J13.1 (In), JP4.1 (A), RV4.1
unnamed: J14.1 (In), U21.6 (2IN-), U21.7 (2OUT)
unnamed: J15.1 (In), U22.6 (2IN-), U22.7 (2OUT)
unnamed: J16.1 (In), U21.1 (1OUT), U21.2 (1IN-)
unnamed: J17.1 (In), U22.1 (1OUT), U22.2 (1IN-)
unnamed: JP3.2 (C), JP3.3 (B), R3.1
unnamed: JP4.2 (C), JP4.3 (B), R4.1
unnamed: JP5.1 (A), U11.11 (OUT+)
unnamed: JP5.3 (B), U11.9 (OUT-)
unnamed: JP6.1 (A), U12.11 (OUT+)
unnamed: JP6.3 (B), U12.9 (OUT-)
unnamed: R5.1, U11.3 (+IN)
unnamed: R6.1, U12.3 (+IN)

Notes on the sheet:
ACP Entrada Radar
ARP Entrada Radar
U1X: Comparadores Tensión de señal de entrada máxima 12 V Tensión de señal de salida 5V
U2X: Amplificadores operacionales Salidas duplicadas para otros equipos Tensión de salida: 5V
U3X: Convertidor de Niveles Lógicos Tensión de señal de entrada 5 V Tensión de señal de salida 3.3V
JP3 Selección de Carga de Entrada R3
JP4 Selección de Carga de Entrada R4
JP5 Selección salida negada
JP6 Selección salida negada

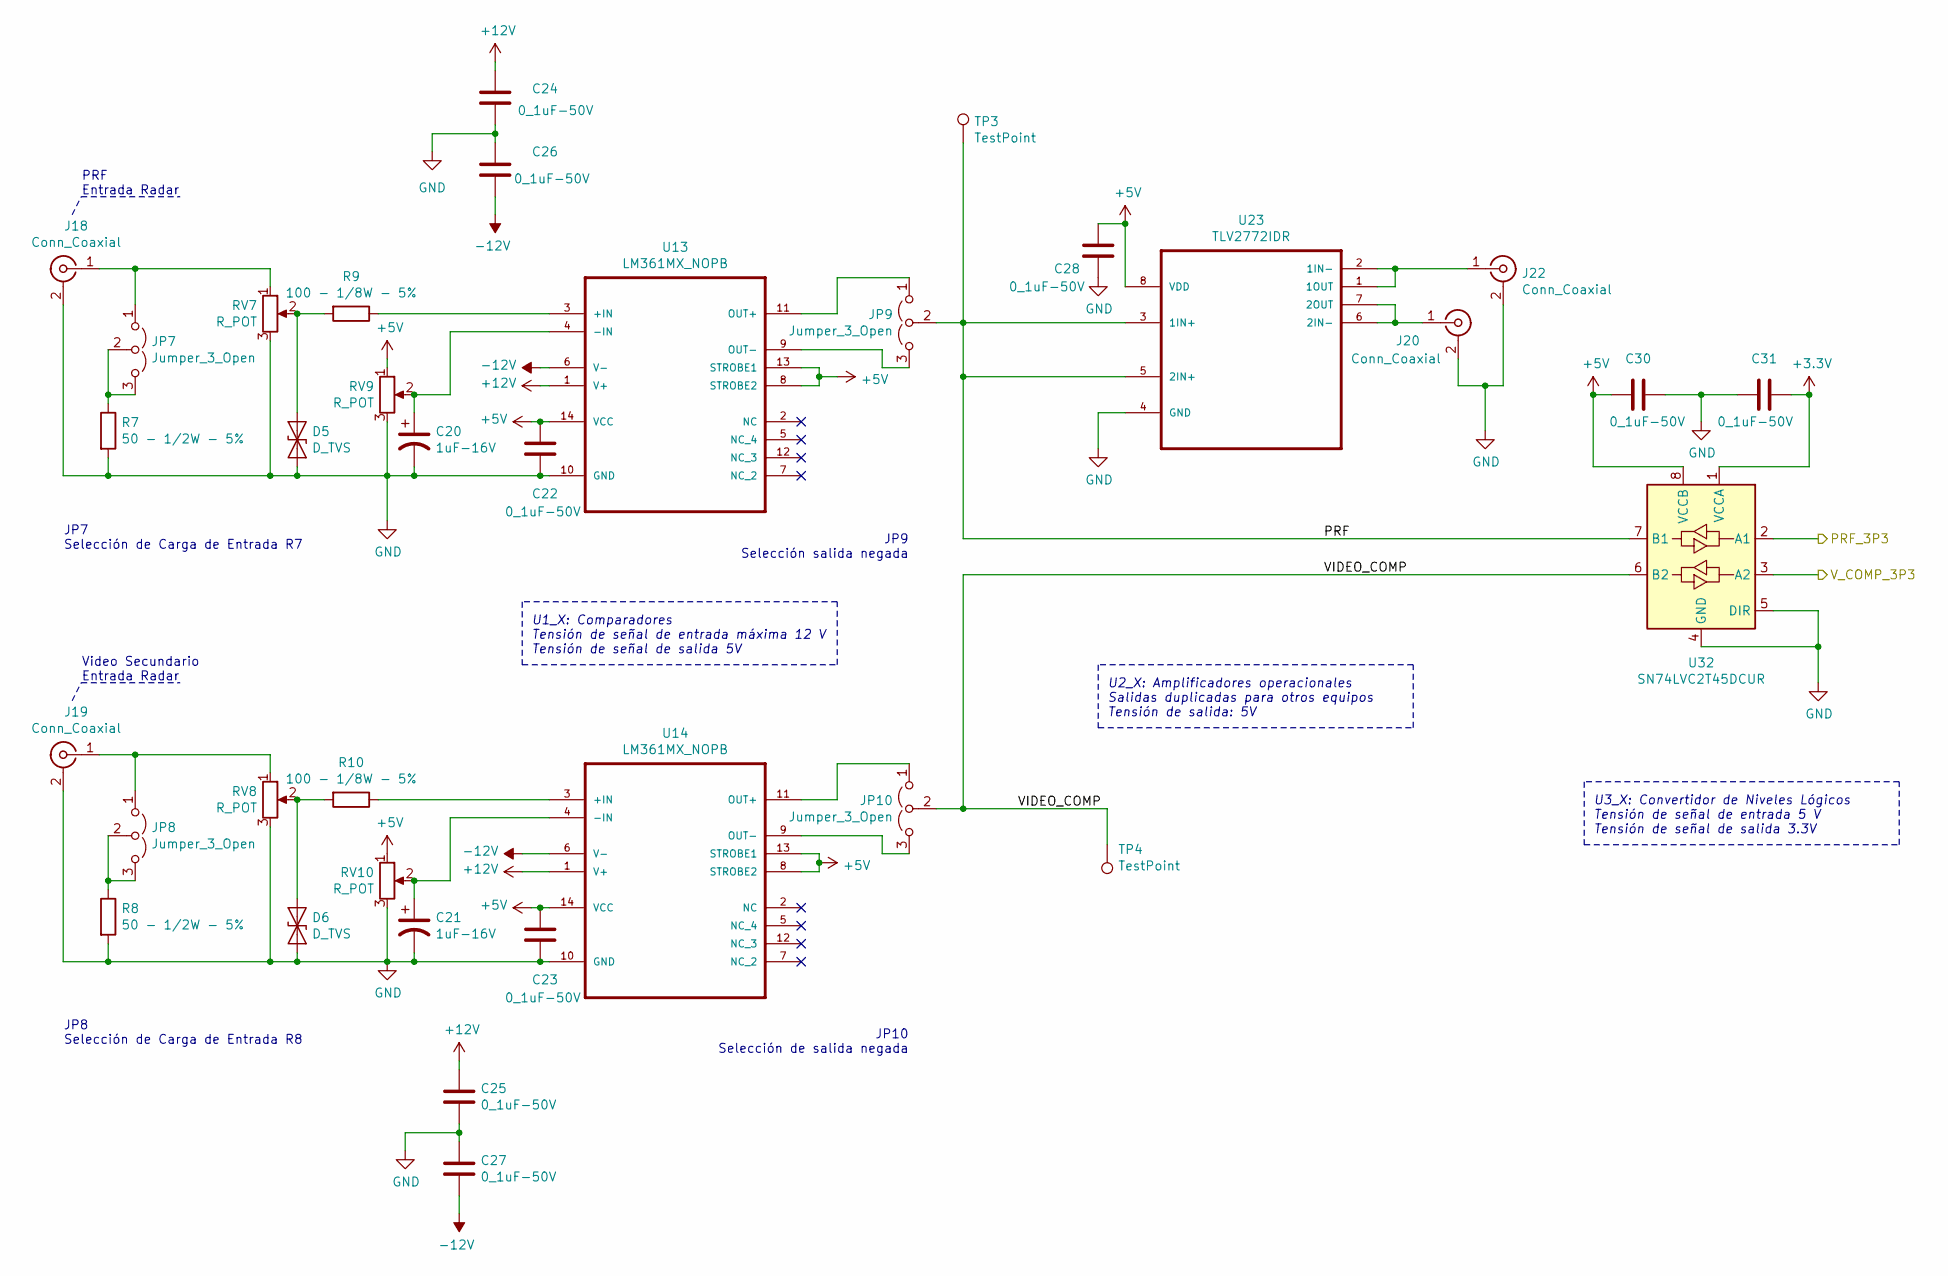
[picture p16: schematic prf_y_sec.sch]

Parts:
C20, C21: 1uF-16V; R_1206_3216Metric
C22, C23, C24, C25, C26, C27, C28, C30, C31: 0_1uF-50V; C_0805_2012Metric
D5, D6: D_TVS; D_DO-15_P10.16mm_Horizontal
J18, J19, J20, J22: Conn_Coaxial; SMA_Amphenol_901-144_Vertical
JP7, JP8, JP9, JP10: Jumper_3_Open; PinHeader_1x03_P2.54mm_Vertical
R7, R8: 50 - 1/2W - 5%; R_Axial_DIN0414_L11.9mm_D4.5mm_P15.24mm_Horizontal
R9, R10: 100 - 1/8W - 5%; R_0805_2012Metric
RV7, RV8, RV9, RV10: R_POT; Potentiometer_Bourns_3296W_Vertical
TP3, TP4: TestPoint; TestPoint_THTPad_1.5x1.5mm_Drill0.7mm
U13, U14: LM361MX_NOPB; DIP-14_W7.62mm_Socket
U23: TLV2772IDR; SOIC-8_3.9x4.9mm_P1.27mm
U32: SN74LVC2T45DCUR; VSSOP-8_2.4x2.1mm_P0.5mm

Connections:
+3V3: C31.1, U32.1 (VCCA); also elsewhere on the board
+5V: C22.2, C23.2, C28.1, C30.2, RV9.1, RV10.1, U13.8 (STROBE2), U13.13 (STROBE1), U13.14 (VCC), U14.8 (STROBE2), U14.13 (STROBE1), U14.14 (VCC), U23.8 (VDD), U32.8 (VCCB); also elsewhere on the board
+12V: C24.1, C25.1, U13.1 (V+), U14.1 (V+); also elsewhere on the board
-12V: C26.2, C27.2, U13.6 (V-), U14.6 (V-); also elsewhere on the board
/PRF_3P3: U32.2 (A1); also elsewhere on the board
/Señales de Video Secundario y PRF/PRF: JP9.2 (C), TP3.1, U23.3 (1IN+), U23.5 (2IN+), U32.7 (B1)
/Señales de Video Secundario y PRF/VIDEO_COMP: JP10.2 (C), TP4.1, U32.6 (B2)
/V_COMP_3P3: U32.3 (A2); also elsewhere on the board
GND: C20.2, C21.2, C22.1, C23.1, C24.2, C25.2, C26.1, C27.1, C28.2, C30.1, C31.2, D5.2 (A2), D6.2 (A2), J18.2 (Ext), J19.2 (Ext), J20.2 (Ext), J22.2 (Ext), R7.2, R8.2, RV7.3, RV8.3, RV9.3, RV10.3, U13.10 (GND), U14.10 (GND), U23.4 (GND), U32.4 (GND), U32.5 (DIR); also elsewhere on the board
unnamed: C20.1, RV9.2, U13.4 (-IN)
unnamed: C21.1, RV10.2, U14.4 (-IN)
unnamed: D5.1 (A1), R9.2, RV7.2
unnamed: D6.1 (A1), R10.2, RV8.2
unnamed: J18.1 (In), JP7.1 (A), RV7.1
unnamed: J19.1 (In), JP8.1 (A), RV8.1
unnamed: J20.1 (In), U23.6 (2IN-), U23.7 (2OUT)
unnamed: J22.1 (In), U23.1 (1OUT), U23.2 (1IN-)
unnamed: JP7.2 (C), JP7.3 (B), R7.1
unnamed: JP8.2 (C), JP8.3 (B), R8.1
unnamed: JP9.1 (A), U13.11 (OUT+)
unnamed: JP9.3 (B), U13.9 (OUT-)
unnamed: JP10.1 (A), U14.11 (OUT+)
unnamed: JP10.3 (B), U14.9 (OUT-)
unnamed: R9.1, U13.3 (+IN)
unnamed: R10.1, U14.3 (+IN)

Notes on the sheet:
PRF Entrada Radar
Video Secundario Entrada Radar
U1_X: Comparadores Tensión de señal de entrada máxima 12 V Tensión de señal de salida 5V
U2_X: Amplificadores operacionales Salidas duplicadas para otros equipos Tensión de salida: 5V
U3_X: Convertidor de Niveles Lógicos Tensión de señal de entrada 5 V Tensión de señal de salida 3.3V
JP7 Selección de Carga de Entrada R7
JP8 Selección de Carga de Entrada R8
JP9 Selección salida negada
JP10 Selección de salida negada

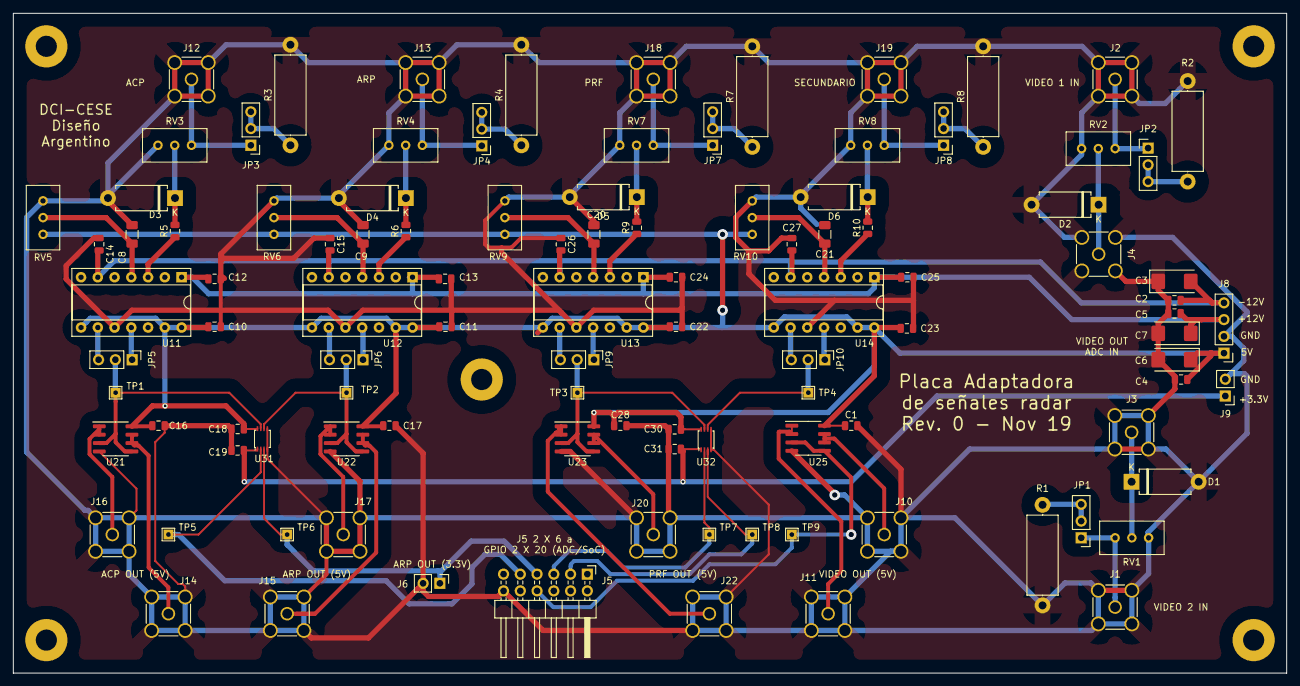
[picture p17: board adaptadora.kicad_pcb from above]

Board: 2 copper layers, 193.0 x 100.0 mm, 110 parts (0 on the bottom side), 56 nets.

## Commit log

2019-10-11 add files, libs, sch videos, sch sincronismo
    [adaptadora.sch, sincronismo.sch, video.sch]
2019-10-18 esquemático terminado faltan valores
    [adaptadora.sch, sincronismo.sch]
2019-10-18 se enumeraron componentes faltan valores
    [adaptadora.sch, sincronismo.sch]
2019-10-18 se agregan valores, etiquetas jerarquicas y poligonos
    [adaptadora.sch, sincronismo.sch]
2019-10-18 se agrega texto
    [adaptadora.sch]
2019-10-18 en proceso de checkeo ERC
    [adaptadora.sch, sincronismo.sch]
2019-10-18 esquemático corregido por compañero
    [adaptadora.sch, sincronismo.sch]
2019-10-25 work in progress
    [acp_y_arp.sch, adaptadora.sch, prf_y_sec.sch]
2019-10-25 correcciones implementadas
    [acp_y_arp.sch, adaptadora.sch, prf_y_sec.sch]
2019-10-26 se agregan huellas, en progreso
    [acp_y_arp.sch, adaptadora.sch, prf_y_sec.sch]
2019-10-31 pcb work in progress
    [acp_y_arp.sch, adaptadora.sch, prf_y_sec.sch]
2019-11-01 Componentes acomodados en PCB
    [acp_y_arp.sch, adaptadora.kicad_pcb, adaptadora.sch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]
2019-11-01 Se dibuja borde de placa
    [adaptadora.kicad_pcb]
2019-11-01 correcciones y archivos agregados
    [acp_y_arp.sch, adaptadora.kicad_pcb, adaptadora.sch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]
2019-11-01 pcb, work in progress
    [adaptadora.csv, adaptadora.kicad_pcb, adaptadora.sch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]
2019-11-02 pcb en proceso de diseño
    [acp_y_arp.sch, adaptadora.csv, adaptadora.kicad_pcb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]
2019-11-07 esq y pcb work in progress
    [adaptadora.kicad_pcb, adaptadora.sch]
2019-11-07 add SMA 3D model & img
    [adaptadora.kicad_pcb]
2019-11-08 mejorando BOM - work in progress
    [BOM_adaptadora_opc1.csv, acp_y_arp.sch, adaptadora.csv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]
2019-11-08 se ordenan campos de integrados
    [acp_y_arp.sch, adaptadora.kicad_pcb, adaptadora.sch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]
2019-11-16 agrego modelo 3d lm361 sobre el sócalo
    [adaptadora.kicad_pcb]
2019-11-16 se cambia footprint de componentes y el posicionamiento
    [BOM_adaptadora_opc1.csv, acp_y_arp.sch, adaptadora.csv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]
2019-11-16 creo librerías de huellas y modelos 3D
2019-11-17 ruteo en proceso
    [adaptadora.kicad_pcb]
2019-11-18 ultimo commit antes de quitar dac del esq
    [adaptadora.kicad_pcb]
2019-11-18 se quita el gpio 2x20 por un 2x6
    [adaptadora.sch]
2019-11-19 se agrega planos de tierra
    [acp_y_arp.sch, adaptadora.kicad_pcb, adaptadora.sch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]
2019-11-22 modificaciones bom
    [acp_y_arp.sch, adaptadora.kicad_pcb, prf_y_sec.sch]
2019-11-23 se suben nuevamente
    [adaptadora.kicad_pcb]
2019-11-23 se cambian rutas de modelos 3D y se sube .step de sma vert
    [User Library-5-1814832-1.STEP, adaptadora.kicad_pcb]
